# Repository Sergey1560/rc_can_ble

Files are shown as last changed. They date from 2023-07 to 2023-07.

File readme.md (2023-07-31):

# RaceChrono BLE CAN и GPS адаптер

[English version](./readme_en.md)

GPS приемник и CAN адаптер для работы с [RaceChrono](https://racechrono.com/) через BLE ([подробности протокола](https://github.com/aollin/racechrono-ble-diy-device)). 

В качестве управляющего МК использован NRF52840. Для упрощения сборки используется готовый модуль [Ebyte E73-2G4M08S1C](https://aliexpress.ru/item/1005004834868792.html) ([datasheet](./doc/S1C_Usermanual_v1.9.pdf))

В качестве GPS приемника используется [Ublox M9N](https://www.u-blox.com/en/product/neo-m9n-module) с частотой обновления 25Hz.

CAN реализован на [MCP2515](./doc/MCP2515-Stand-Alone-CAN-Controller-with-SPI-20001801J.pdf) и транссивере SN65HVD230. Для упрощения покупки mcp2515 снята с [готового модуля](https://aliexpress.ru/item/32817132818.html), с которого так же был снят кварц и конденсаторы кварца.

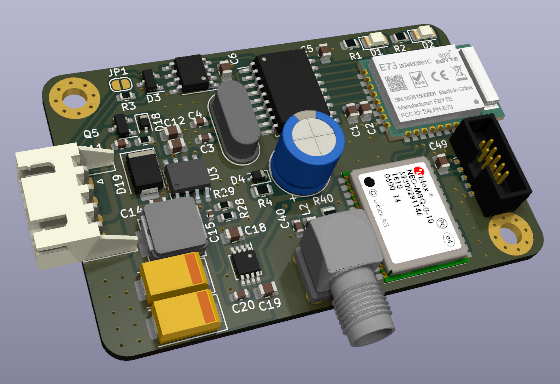
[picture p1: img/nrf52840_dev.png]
device render


[Схема](./shematic/nrf52840_dev.pdf)

Проект выполнен в Kicad 7.

## Список компонентов

Интерактивный BOM находится в bom/ibom.html

| Элемент | Количество | Номинал | Посадочное место | Описание
| --- | --- | --- | --- | ---
|C1, C18, C19|3|1uF|Capacitor_SMD:C_0805_2012Metric| |
|C2, C12 |2|10uF|Capacitor_SMD:C_0805_2012Metric| | 
|C3, C4 |2|C_Small|Capacitor_SMD:C_0603_1608Metric|Сняты с модуля CAN|
|C5, C6, C13, C14, C49|5|0.1uF|Capacitor_SMD:C_0805_2012Metric| |
|C7|1|1F|Capacitor_THT:CP_Radial D8.0mm_P3.50mm|Используется как источник резервного питания GPS модуля|
|C11, C20, C40|3|0.01uF|Capacitor_SMD:C_0603_1608Metric| |
|C15|1|1.6pF|Capacitor_SMD:C_0402_1005Metric| |
|C16, C17|2|47uF|Capacitor_Tantalum SMD:CP_EIA-7343-31_Kemet-D| |
|D1, D2|  2|LED_Small|LED_SMD:LED_1206_3216Metric| |
|D3 |1|NUP2105L|Package_TO_SOT_SMD:SOT-23|Dual Line CAN Bus Protector, 24Vrwm|
|D4 |1|1N4148|Diode_SMD:D_SOD-323| |
|D18 |1|BZT52C16S|Diode_SMD:D_SOD-323| |
|D19 |1|STPS2L25|Diode_SMD:D_SMB"| |
|J1|1|Conn 01x04|JST_XH_S4B-XH-A-1_1x04_P2.50mm_Horizontal| |
|J2|1|Coaxial Power|SMA_Amphenol_901-144_Vertical| |
|J3|1|SWD|PinHeader_2x05_P1.27mm_Vertical_SMD| |
|L1|1|8.2uH|power:Inductor8.2| |
|L2|1|27nH|Inductor_SMD:L_0805_2012| |
|Q5|1|AO3401A|Package_TO_SOT_SMD:SOT-23| |
|R1, R2|2|1K|Resistor_SMD:R_0805_2012Metric| |
|R3|1|120|Resistor_SMD:R_0603_1608Metric| |
|R4|1|100|Resistor_SMD:R_0805_2012Metric| |
|R27|1|10K|Resistor_SMD:R_0603_1608Metric| |
|R28|1|187K|Resistor_SMD:R_0603_1608Metric| |
|R29|1|60.4K|Resistor_SMD:R_0603_1608Metric| |
|R40|1|10|Resistor_SMD:R_1206_3216Metric| |
|U1|1|E73-2G4M08S1C|E73-2G4M08S1C-52840| |
|U2|1|MCP2515-xSO|Package_SO:SOIC-18W|Stand-Alone CAN Controller with SPI Interface<br>Снят с модуля CAN|
|U3|1|ST1S14PHR_MY|Package_SO:SOIC-8-1EP| |
|U4|1|NCP3335|Package_SO:OnSemi_Micro8| |
|U5|1|SN65HVD230|Package_SO:SOIC-8|CAN Bus Transceivers, 3.3V, 1Mbps, Low-Power capabilities|
|U17|1|NEO-9M|ublox:NEO-M8N|Ublox M9N|
|Y1|1|8Mhz|Crystal:Crystal_HC49-4H_Vertical|Снят с модуля CAN|

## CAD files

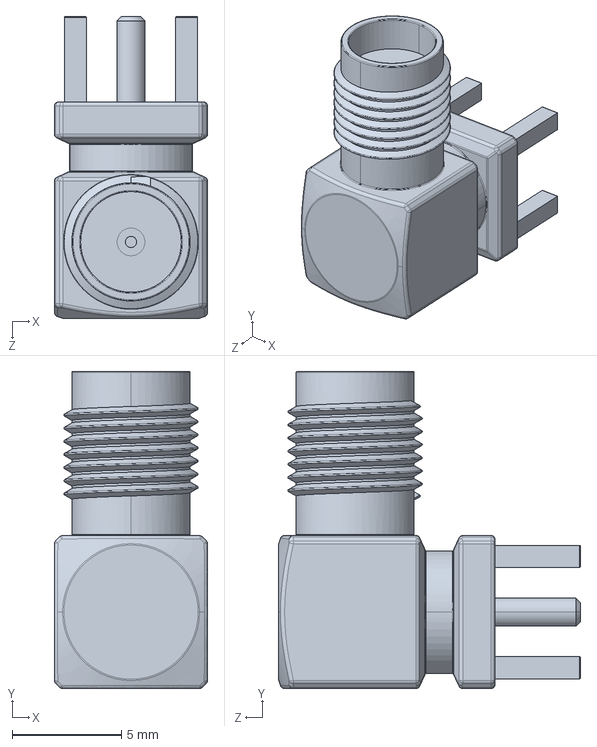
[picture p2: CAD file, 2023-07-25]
3d/SMA ANGLED.STEP
7.00 x 14.5 x 13.8 mm

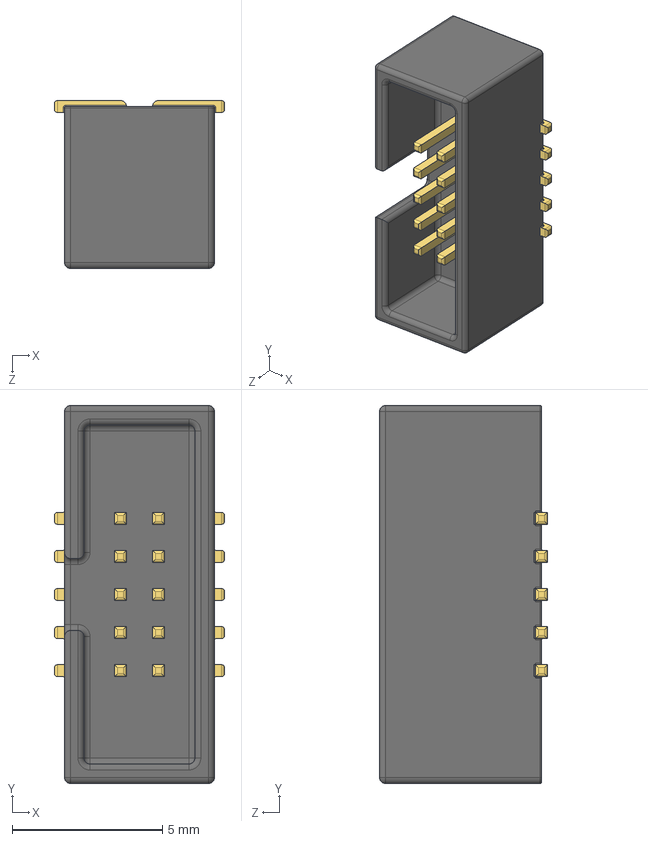
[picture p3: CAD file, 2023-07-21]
3d/IDC2x05_SMD.STEP
5.67 x 12.6 x 5.60 mm

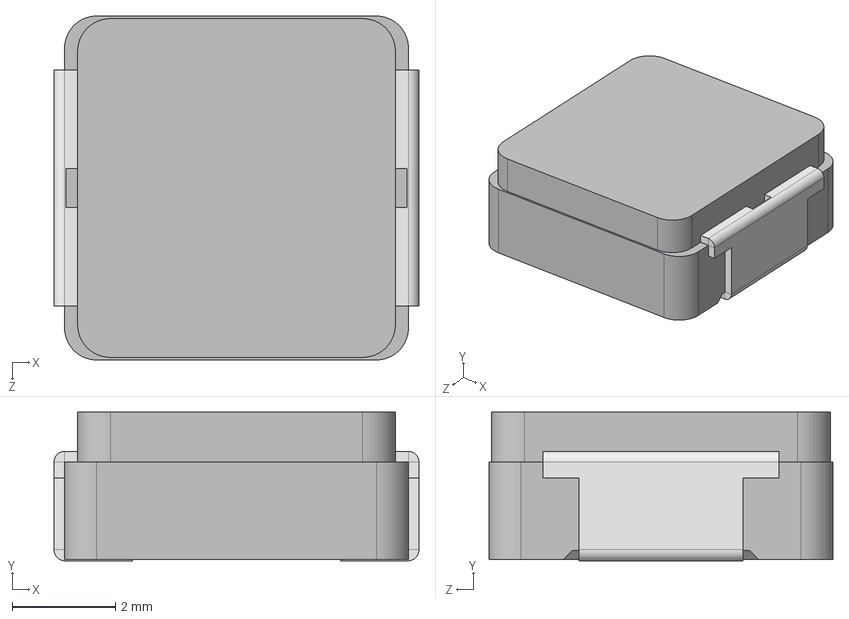
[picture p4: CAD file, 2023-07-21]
3d/IHLP2525CZER8R2M01.stp
7.08 x 2.88 x 6.67 mm

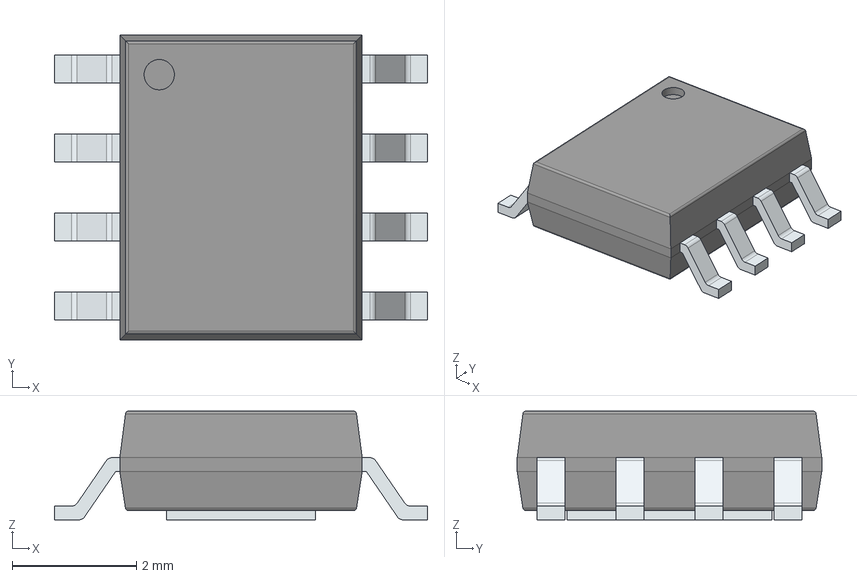
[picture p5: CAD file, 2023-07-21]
3d/ST1S14PHR.step
6.00 x 4.90 x 1.75 mm
PinsArrayLR
ThermalPad

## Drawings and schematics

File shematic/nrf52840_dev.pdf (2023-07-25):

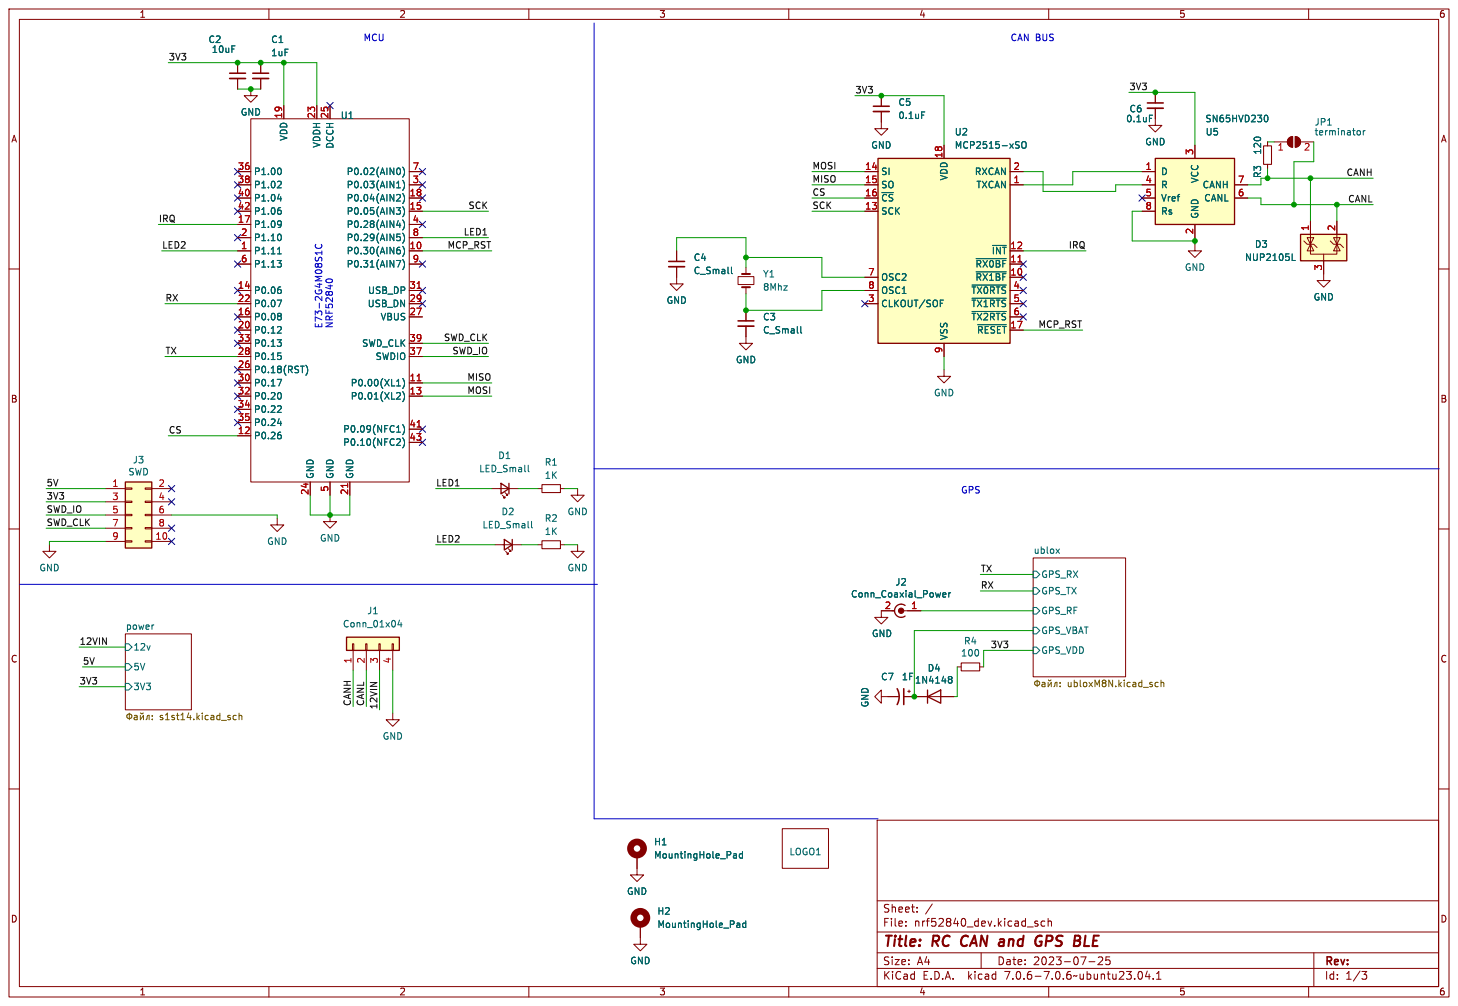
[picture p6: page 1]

5 P1.13 6 P0.02(AIN0) 7 P0.29(AIN5) 8 P0.31(AIN7) 9 U1 TXCAN 1 ~{RX1BF}10 ~{RX0BF}11 ~{INT} 12 SCK 13 SI 14 SO 15 ~{CS} 16 ~{RESET} 17 VDD 18 RXCAN 2 CLKOUT/SOF 3 ~{TX0RTS}4 ~{TX1RTS}5 ~{TX2RTS}6 OSC2 7 OSC1 8 VSS

RX MCP_RST SCK CANH CANL

Id: 1/3 Title: RC CAN and GPS BLE

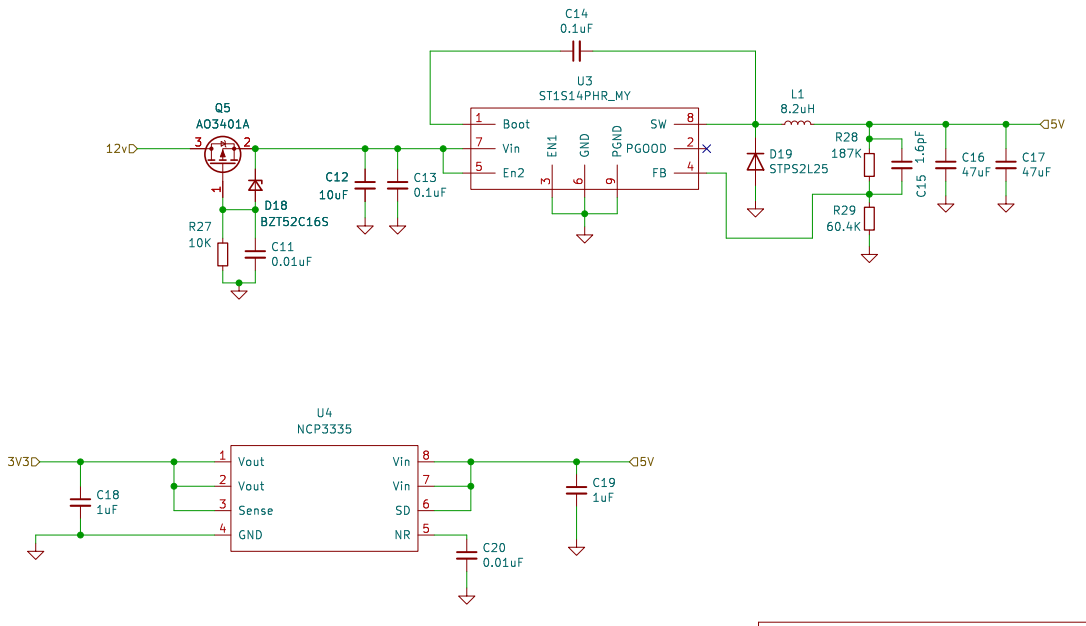
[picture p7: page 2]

File: s1st14.kicad_sch Sheet: /power/ DC/DC

Id: 2/3 Title: RC CAN and GPS BLE

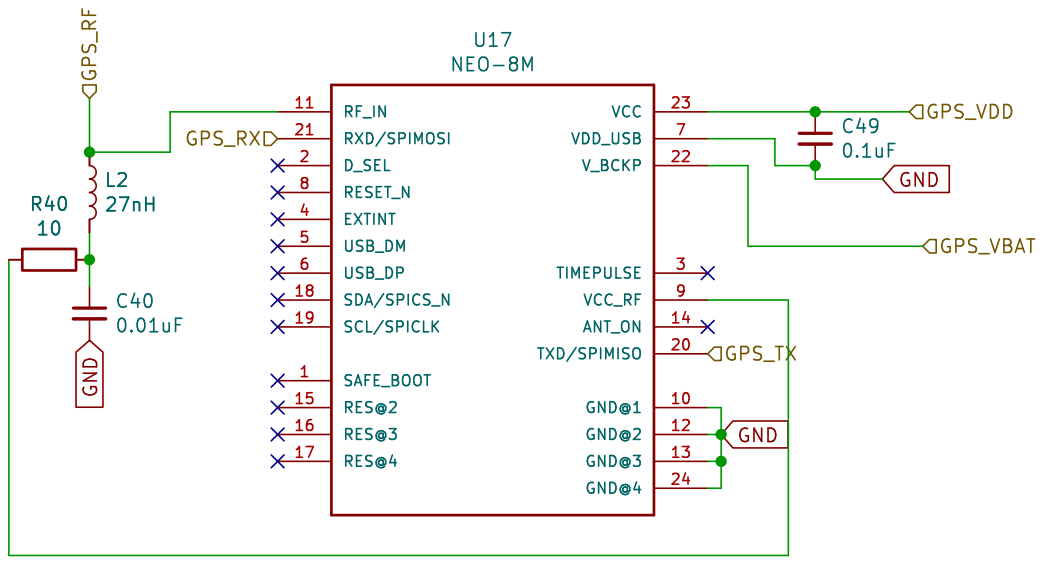
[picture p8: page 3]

Id: 3/3 Title: RC CAN and GPS BLE

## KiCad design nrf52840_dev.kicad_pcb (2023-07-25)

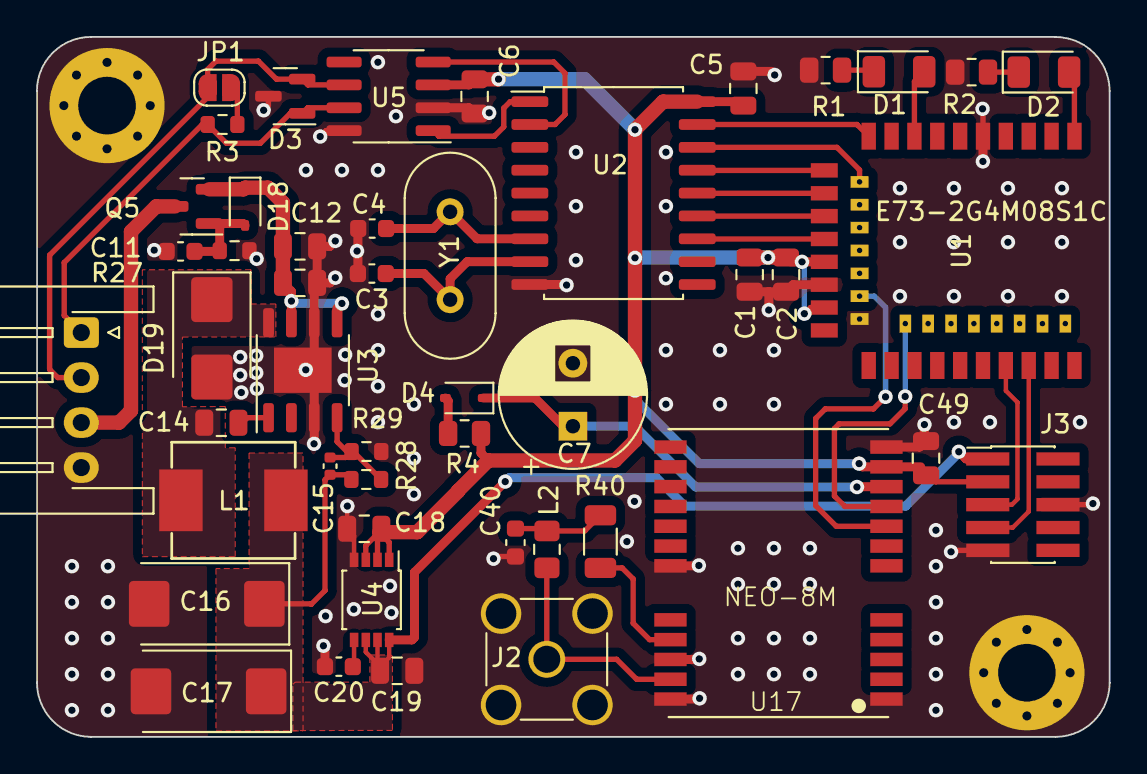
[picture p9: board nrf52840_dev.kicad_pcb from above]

Board: 2 copper layers, 59.6 x 38.9 mm, 50 parts (1 on the bottom side), 36 nets.

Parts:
C1, C18, C19: 1uF; C_0805_2012Metric
C2, C12: 10uF; C_0805_2012Metric
C3, C4: C_Small; C_0603_1608Metric
C5, C6, C13, C14, C49: 0.1uF; C_0805_2012Metric
C7: 1F; CP_Radial_D8.0mm_P3.50mm
C11, C20, C40: 0.01uF; C_0603_1608Metric
C15: 1.6pF; C_0402_1005Metric
C16, C17: 47uF; CP_EIA-7343-31_Kemet-D_Pad2.25x2.55mm_HandSolder
D1, D2: LED_Small; LED_1206_3216Metric
D3: NUP2105L; SOT-23
D4: 1N4148; D_SOD-323
D18: BZT52C16S; D_SOD-323
D19: STPS2L25; D_SMB
H1, H2: MountingHole_Pad; MountingHole_3.2mm_M3_Pad_Via
J1: Conn_01x04; JST_XH_S4B-XH-A-1_1x04_P2.50mm_Horizontal
J2: Conn_Coaxial_Power; SMA_Amphenol_901-144_Vertical
J3: SWD; PinHeader_2x05_P1.27mm_Vertical_SMD
JP1: terminator; SolderJumper-2_P1.3mm_Open_RoundedPad1.0x1.5mm
L1: 8.2uH; Inductor8.2
L2: 27nH; L_0805_2012Metric_Pad1.15x1.40mm_HandSolder
LOGO1: logo_15x9
Q5: AO3401A; SOT-23
R1, R2: 1K; R_0805_2012Metric
R3: 120; R_0603_1608Metric
R4: 100; R_0805_2012Metric
R27: 10K; R_0603_1608Metric
R28: 187K; R_0603_1608Metric
R29: 60.4K; R_0603_1608Metric
R40: 10; R_1206_3216Metric
U1: E73-2G4M08S1C-52840
U2: MCP2515-xSO; SOIC-18W_7.5x11.6mm_P1.27mm
U3: ST1S14PHR_MY; SOIC-8-1EP_3.9x4.9mm_P1.27mm_EP2.514x3.2mm
U4: NCP3335; OnSemi_Micro8
U5: SN65HVD230; SOIC-8_3.9x4.9mm_P1.27mm
U17: NEO-8M; NEO-M8N
Y1: 8Mhz; Crystal_HC49-4H_Vertical

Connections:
/3V3: C1.1, C2.1, C5.1, C6.1, C18.1, C49.1, J3.3, R4.1, U1.19 (VDD), U1.23 (VDDH), U2.18 (VDD), U4.1 (Vout), U4.2 (Vout), U4.3 (Sense), U5.3 (VCC), U17.23 (VCC)
/5V: C15.1, C16.1, C17.1, C19.1, J3.1, L1.2, R28.1, U4.6 (SD), U4.7 (Vin), U4.8 (Vin)
/12VIN: J1.3, Q5.3 (D)
/CANH: D3.1 (K), J1.1, R3.1, U5.7 (CANH)
/CANL: D3.2 (K), J1.2, JP1.2 (B), U5.6 (CANL)
/CS: U1.12 (P0.26), U2.16 (~CS)
/IRQ: U1.17 (P1.09), U2.12 (~INT)
/LED1: D1.2 (A), U1.8 (P0.29(AIN5))
/LED2: D2.2 (A), U1.1 (P1.11)
/MCP_RST: U1.10 (P0.30(AIN6)), U2.17 (~RESET)
/MISO: U1.11 (P0.00(XL1)), U2.15 (SO)
/MOSI: U1.13 (P0.01(XL2)), U2.14 (SI)
/RX: U1.22 (P0.07), U17.20 (TXD/SPIMISO)
/SCK: U1.15 (P0.05(AIN3)), U2.13 (SCK)
/SWD_CLK: J3.7, U1.39 (SWD_CLK)
/SWD_IO: J3.5, U1.37 (SWDIO)
/TX: U1.28 (P0.15), U17.21 (RXD/SPIMOSI)
/ublox/GPS_RF: J2.1 (In), L2.1, U17.11 (RF_IN)
/ublox/GPS_VBAT: C7.1, D4.1 (K), U17.22 (V_BCKP)
GND: C1.2, C2.2, C3.2, C4.2, C5.2, C6.2, C7.2, C11.2, C12.2, C13.2, C16.2, C17.2, C18.2, C19.2, C20.2, C40.2, C49.2, D3.3 (A), D19.2 (A), H1.1, H2.1, J1.4, J2.2 (Ext), J3.6, J3.9, R1.2, R2.2, R27.2, R29.2, U1.5 (GND), U1.21 (GND), U1.24 (GND), U2.9 (VSS), U3.3 (EN1), U3.6 (GND), U3.9 (PGND), U4.4 (GND), U5.2 (GND), U5.8 (Rs), U17.7 (VDD_USB), U17.10 (GND@1), U17.12 (GND@2), U17.13 (GND@3), U17.24 (GND@4)
unnamed: C40.1, L2.2, R40.1
unnamed: D1.1 (K), R1.1
unnamed: D2.1 (K), R2.1
unnamed: D4.2 (A), R4.2
unnamed: C11.1, D18.2 (A), Q5.1 (G), R27.1
unnamed: C12.1, C13.1, D18.1 (K), Q5.2 (S), U3.5 (En2), U3.7 (Vin)
unnamed: C14.2, D19.1 (K), L1.1, U3.8 (SW)
unnamed: JP1.1 (A), R3.2
unnamed: C3.1, U2.8 (OSC1), Y1.1
unnamed: C4.1, U2.7 (OSC2), Y1.2
unnamed: U2.2 (RXCAN), U5.4 (R)
unnamed: U2.1 (TXCAN), U5.1 (D)
unnamed: C14.1, U3.1 (Boot)
unnamed: C15.2, R28.2, R29.1, U3.4 (FB)
unnamed: C20.1, U4.5 (NR)
unnamed: R40.2, U17.9 (VCC_RF)

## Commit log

2023-06-28 CNC test board
    [nrf52840_dev.kicad_pcb, nrf52840_dev.kicad_sch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]
2023-07-21 Small fix
    [IDC2x05_SMD.STEP, IHLP2525CZER8R2M01.stp, ST1S14PHR.stp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]
2023-07-25 Update production files, add schematic
    [nrf52840_dev-B_Cu.gbr, nrf52840_dev-B_Mask.gbr, nrf52840_dev-B_Paste.gbr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]
2023-07-25 BOM layout
